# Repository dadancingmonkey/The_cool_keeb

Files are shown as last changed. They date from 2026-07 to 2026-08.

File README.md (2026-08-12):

The CoolKeeb

Description
The CoolKeeb is a cool custom keyboard that was fully designed and made by me. 
It is a general gaming keyboard that has a premium enclosure and bluetooth wireless cabilities whille retaining RGB illumination. 

It includes:
- custom PCB that hosues the switches
- Hotswappable sockets 
- exploded 75% format with 80 keys + a volume knob
- Nice!Nano MCU 
- 2000mAh battery 
- Cherry MX Brown switches
- Per-Key RGB illumination
- side printed PBT keycaps
- 3d printed & aluminum sheetmetal enclosure

images:
Screenshot 2026-07-09 at 5 52 30 PM
Screenshot 2026-07-09 at 5 53 01 PM
Screenshot 2026-07-09 at 5 53 17 PM

Schematics: 
Screenshot 2026-07-24 at 12 16 46 PM

PCB:


Assembly instructions:
- Solder the Kailh hot-swap inserts to the shield/keybaord board
- Solder all relavant components using schematic (diodes, LEDs, MCU, etc.)
- Attach MX switches to the keyboard plate
- Set MX switches into the hot-swap inserts
- Assemble the enclosure with 3D-printed parts and CNC aluminum parts.
- The case is essentially sandwiched using M3 screws, with the top 3D-printed elments being press-fit. 

Exploded view of enclosure assembly:
Screenshot 2026-07-24 at 11 02 27 PM

BOM: 
| Part | Price (USD) | Quantity | Source |
|---|---:|:---:|---|
| PBT keycaps, shine-through side printed | $17.65 | 1 | https://www.amazon.ca/dp/B0D1XK549B?psc=1&ref_=cm_sw_r_cp_ud_ct_RZ4HP9B0TKT2E4PN34CX |
| 466pcs M3 assorted screw kit | $12.00 | 1 | https://www.amazon.ca/dp/B0GCF8HZFR?psc=1&ref_=cm_sw_r_cp_ud_ct_RZ4HP9B0TKT2E4PN34CX_1 |
| 110pcs Kailh hot-swap PCB socket | $9.88 | 1 | https://www.aliexpress.com/item/1005012011087592.html |
| Cherry-style clear PCB-mounted stabilizers | $7.89 | 1 | https://www.aliexpress.com/item/32719735398.html |
| 50g rosin core solder | $5.04 | 1 | https://www.aliexpress.com/item/32889029087.html |
| NRF52840 dev board (Nice!Nano clone) | $4.00 | 1 | https://www.aliexpress.com/item/1005008594178678.html |
| 90pcs Cherry MX Brown RGB switches | $28.79 | 1 | https://www.aliexpress.com/item/1005008998414457.html |
| 5pcs round hole pin header | $3.12 | 1 | https://www.aliexpress.com/item/4001122376295.html |
| 100pcs JST PH 2-pin plug (male & female) | $1.99 | 1 | https://www.aliexpress.com/item/1005004955655144.html |
| 100pcs 1N4148WS T4 diodes | $3.45 | 1 | https://www.aliexpress.com/item/1005004309686841.html |
| 3.7V 2000mAh Li-Po battery | $7.08 | 1 | https://www.aliexpress.com/item/1005011848043177.html |
| 100pcs SK6803MINI-E LEDs | $10.86 | 1 | https://www.aliexpress.com/item/1005006968060177.html |
| Shipping (AliExpress) | $5.46 | 1 | N/A |
| EC11 rotary encoder | $0.00 | 1 | Me |
| PCB | $21.80 | 1 (5 pcs) | JLCPCB |
| Aluminum switch plate | $16.48 | 1 | JLCCNC |
| Aluminum cosmetic plate | $5.19 | 1 | JLCCNC |
| Aluminum bottom plate | $11.03 | 1 | JLCCNC |
| Aluminum bottom subframe plate | $10.40 | 1 | JLCCNC |
| PLA 3D printing filament + machine time | $5.00 | 1 | me |
| Shipping (JLCPCB/CNC, DHL Express) | $31.77 | 1 | DHL Express |

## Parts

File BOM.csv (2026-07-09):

part | price(USD) | quantity | source
PBT keycaps shinethrough side printed | $17.65 | 1 | https://www.amazon.ca/dp/B0D1XK549B?psc=1&ref_=cm_sw_r_cp_ud_ct_RZ4HP9B0TKT2E4PN34CX
466pcs M3 assorted screw kit | $12.00 | 1 | https://www.amazon.ca/dp/B0GCF8HZFR?psc=1&ref_=cm_sw_r_cp_ud_ct_RZ4HP9B0TKT2E4PN34CX_1
110pcs kailh Hot-swap PCB socket | $9.88 | 1 | https://www.aliexpress.com/item/1005012011087592.html?mp=1
Cherry Style clear PCB-mounted stabilizers | $7.89 | 1 | https://www.aliexpress.com/item/32719735398.html?mp=1
50g Rosin Core solder | $5.04 | 1 | https://www.aliexpress.com/item/32889029087.html?mp=1
NRF52840 dev board (Nice!Nano clone) | $4.00 | 1 | https://www.aliexpress.com/item/1005008594178678.html?mp=1
90pcs Cherry MX Brown RGB switch | $28.79 | 1 | https://www.aliexpress.com/item/1005008998414457.html?mp=1
5pcs round hole pin header | $3.12 | 1 | https://www.aliexpress.com/item/4001122376295.html?mp=1
100pcs JST PH 2 pin plug male and female | $1.99 | 1 | https://www.aliexpress.com/item/1005004955655144.html?mp=1
100pcs 1N4148WS T4 diode | $3.45 | 1 | https://www.aliexpress.com/item/1005004309686841.html?mp=1
3.7V 2000mAh Li-Po battery | $7.08 | 1 | https://www.aliexpress.com/item/1005011848043177.html?mp=1
100pcs SK6803MINI-E LED | $10.86 | 1 | https://www.aliexpress.com/item/1005006968060177.html?mp=1
Shipping (Aliexpress) | $5.46 | 1 | N/A
EC11 rotary encoder | $0.00 | 1 | me
PCB | $21.80 | 1(5) | JLCPCB
Aluminum switch plate | $16.48 | 1 | JLCCNC
Aluminum cosmetic plate | $5.19 | 1 | JLCCNC
Aluminum bottom plate | $11.03 | 1 | JLCCNC
Aluminum bottom subframe plate | $10.40 | 1 | JLCCNC
Shipping (JLCPCB/CNC) (global star shipping not availible due to weight) | $31.77 | 1 | DHL express

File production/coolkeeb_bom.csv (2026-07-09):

Designator | Footprint | Quantity | Value | LCSC Part #
D1, D10, D11, D12, D13, D14, D15, D16, D17, D18, D19, D2, D20, D21, D22, D23, D24, D25, D26, D27, D28, D29, D3, D30, D31, D32, D33, D34, D35, D36, D37, D38, D39, D4, D40, D41, D42, D43, D44, D45, D46, D47, D48, D49, D5, D50, D51, D52, D53, D54, D55, D56, D57, D58, D59, D6, D60, D61, D62, D63, D64, D65, D66, D67, D68, D69, D7, D70, D71, D72, D73, D74, D75, D76, D77, D78, D79, D8, D80, D81, D9 | D_SOD-323 | 81 | 1N4148WS | C57759
J1-BATTERY1 | JST_PH_S2B-PH-K_1x02_P2.00mm_Horizontal | 1 | Conn_01x02_Socket | C514173
LED1, LED10, LED11, LED12, LED13, LED2, LED29, LED3, LED30, LED31, LED32, LED33, LED34, LED35, LED36, LED37, LED38, LED39, LED4, LED40, LED41, LED42, LED43, LED5, LED58, LED59, LED6, LED60, LED61, LED62, LED63, LED64, LED65, LED66, LED67, LED68, LED69, LED7, LED70, LED8, LED9 | LED_MX_6028R-ROT | 41 | MX_SK6812MINI-E | C5242955
LED14, LED15, LED16, LED17, LED18, LED19, LED20, LED21, LED22, LED23, LED24, LED25, LED26, LED27, LED28, LED44, LED45, LED46, LED47, LED48, LED49, LED50, LED51, LED52, LED53, LED54, LED55, LED56, LED57, LED71, LED72, LED73, LED74, LED75, LED76, LED77, LED78, LED79, LED80, LED81, LED82 | LED_MX_6028R | 41 | MX_SK6812MINI-E | C5242955

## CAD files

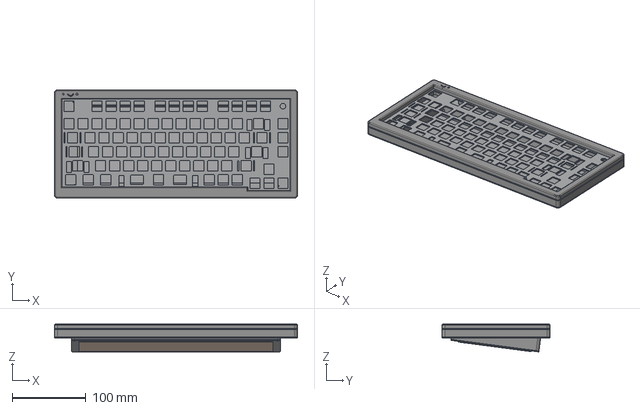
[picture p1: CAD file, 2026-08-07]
CAD/enclosure/assembled.step
329.9 x 147.0 x 37.7 mm

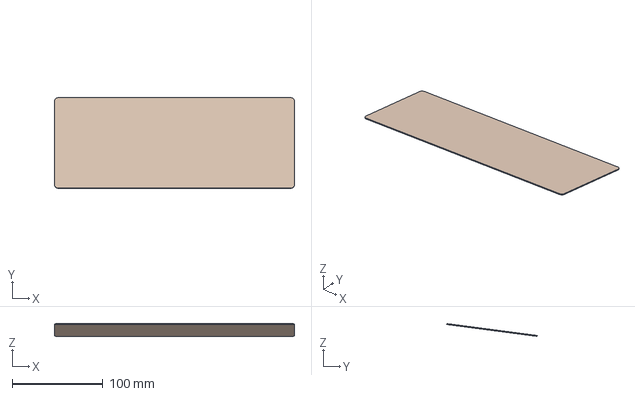
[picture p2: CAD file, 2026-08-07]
CAD/stl file/Part Studio 1 - Part 9.step
263.9 x 99.7 x 14.1 mm

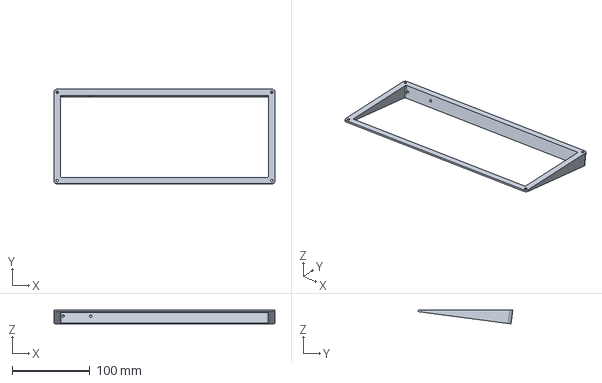
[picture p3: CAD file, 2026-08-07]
CAD/stl file/Part Studio 1 - Part 6.step
284.2 x 121.9 x 17.7 mm

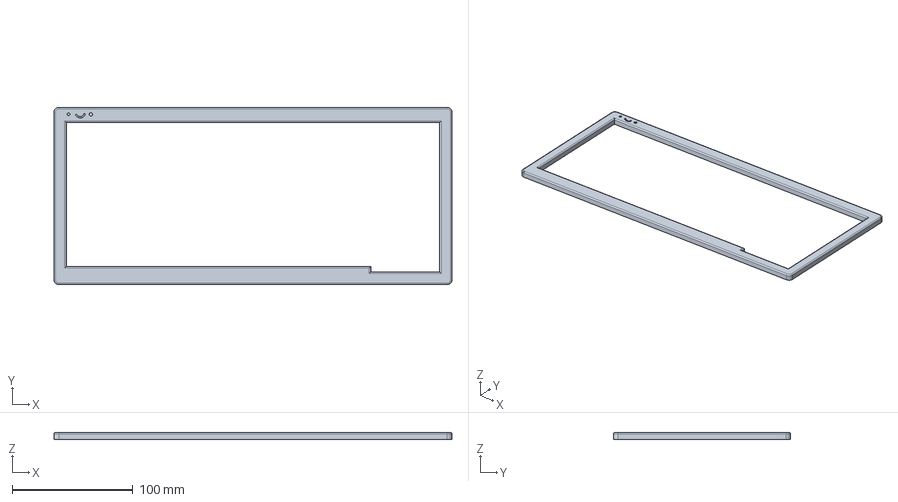
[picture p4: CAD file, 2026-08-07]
CAD/stl file/Part Studio 1 - Part 2.step
329.9 x 147.0 x 6.00 mm

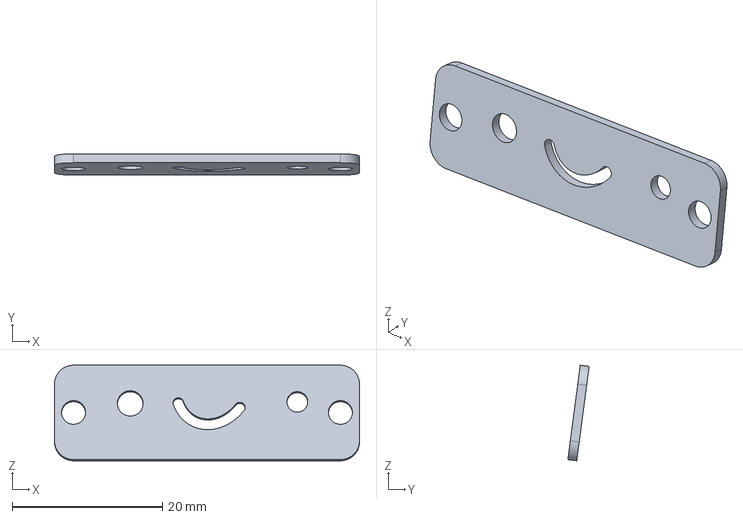
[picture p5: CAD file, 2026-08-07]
CAD/stl file/Part Studio 1 - Part 8.step
40.6 x 2.85 x 12.7 mm

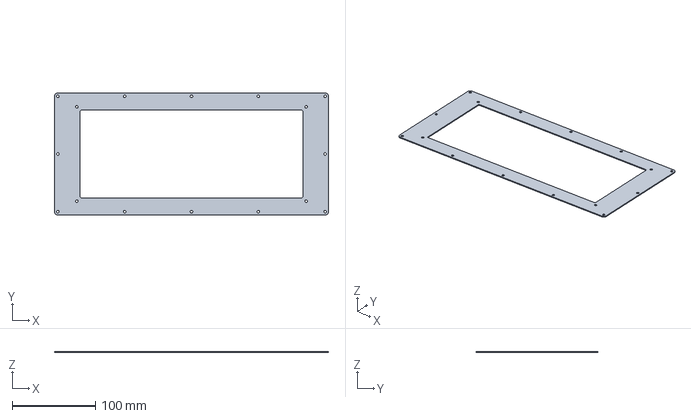
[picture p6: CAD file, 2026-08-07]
CAD/stl file/Part Studio 1 - Part 5.step
329.9 x 147.0 x 1.20 mm

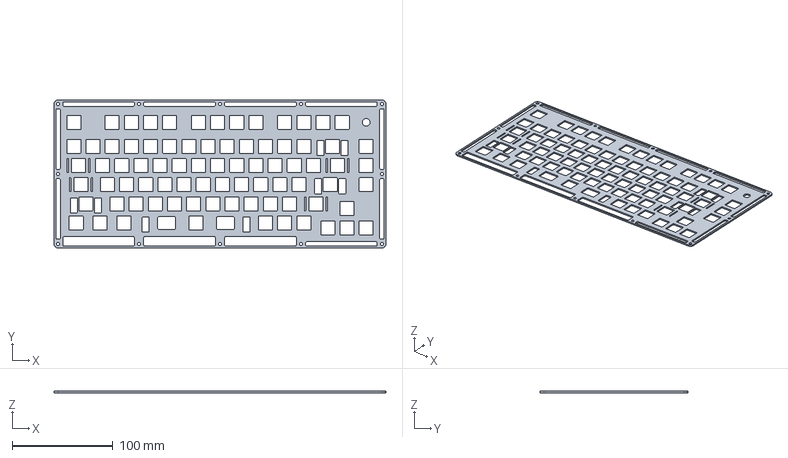
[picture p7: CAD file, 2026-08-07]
CAD/stl file/Part Studio 1 - Part 1.step
329.9 x 147.0 x 1.50 mm

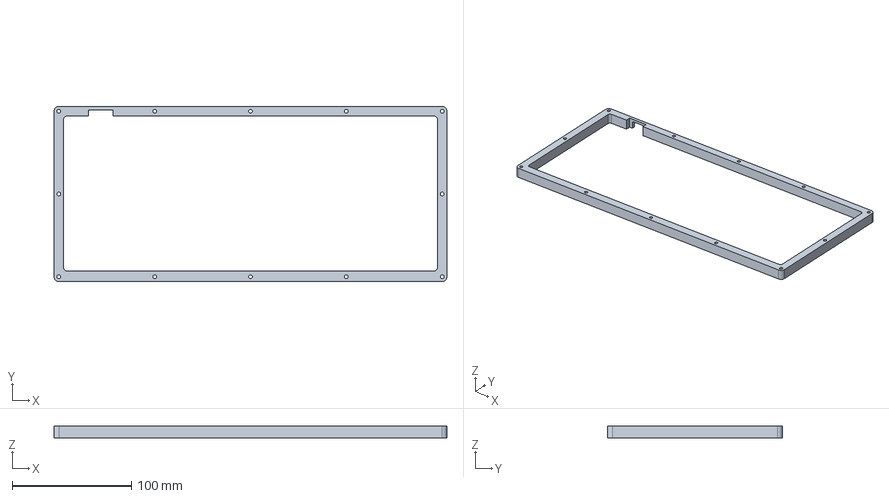
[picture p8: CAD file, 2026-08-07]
CAD/stl file/Part Studio 1 - Part 4.step
329.9 x 147.0 x 10.2 mm

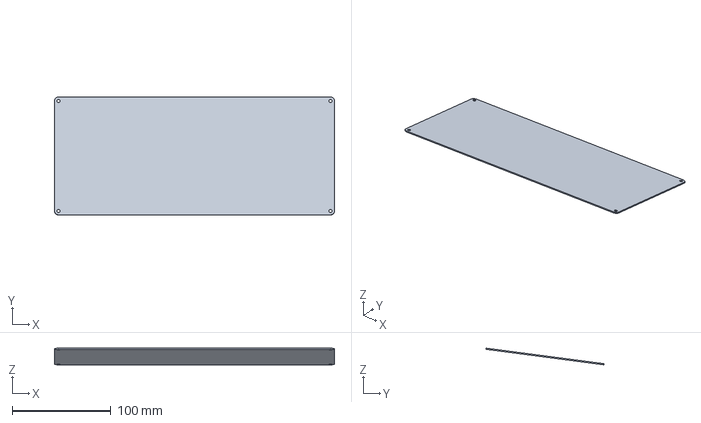
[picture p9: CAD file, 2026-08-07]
CAD/stl file/Part Studio 1 - Part 7.step
284.2 x 119.7 x 16.9 mm

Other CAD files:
CAD/enclosure/Part Studio 1 - Part 1.step
CAD/enclosure/Part Studio 1 - Part 8.step
CAD/enclosure/Part Studio 1 - Part 6.step
CAD/enclosure/Part Studio 1 - Part 2.step
CAD/enclosure/Part Studio 1 - Part 7.step
CAD/enclosure/Part Studio 1 - Part 5.step
CAD/enclosure/Part Studio 1 - Part 4.step
CAD/coolkeeb source/Part Studio 1 - Part 1.x_t
CAD/coolkeeb source/Part Studio 1 - Part 2.x_t
CAD/coolkeeb source/Part Studio 1 - Part 4.x_t
CAD/coolkeeb source/Part Studio 1 - Part 5.x_t
CAD/coolkeeb source/Part Studio 1 - Part 6.x_t
CAD/coolkeeb source/Part Studio 1 - Part 7.x_t
CAD/coolkeeb source/Part Studio 1 - Part 8.x_t
CAD/coolkeeb source/Part Studio 1 - Part 9.x_t

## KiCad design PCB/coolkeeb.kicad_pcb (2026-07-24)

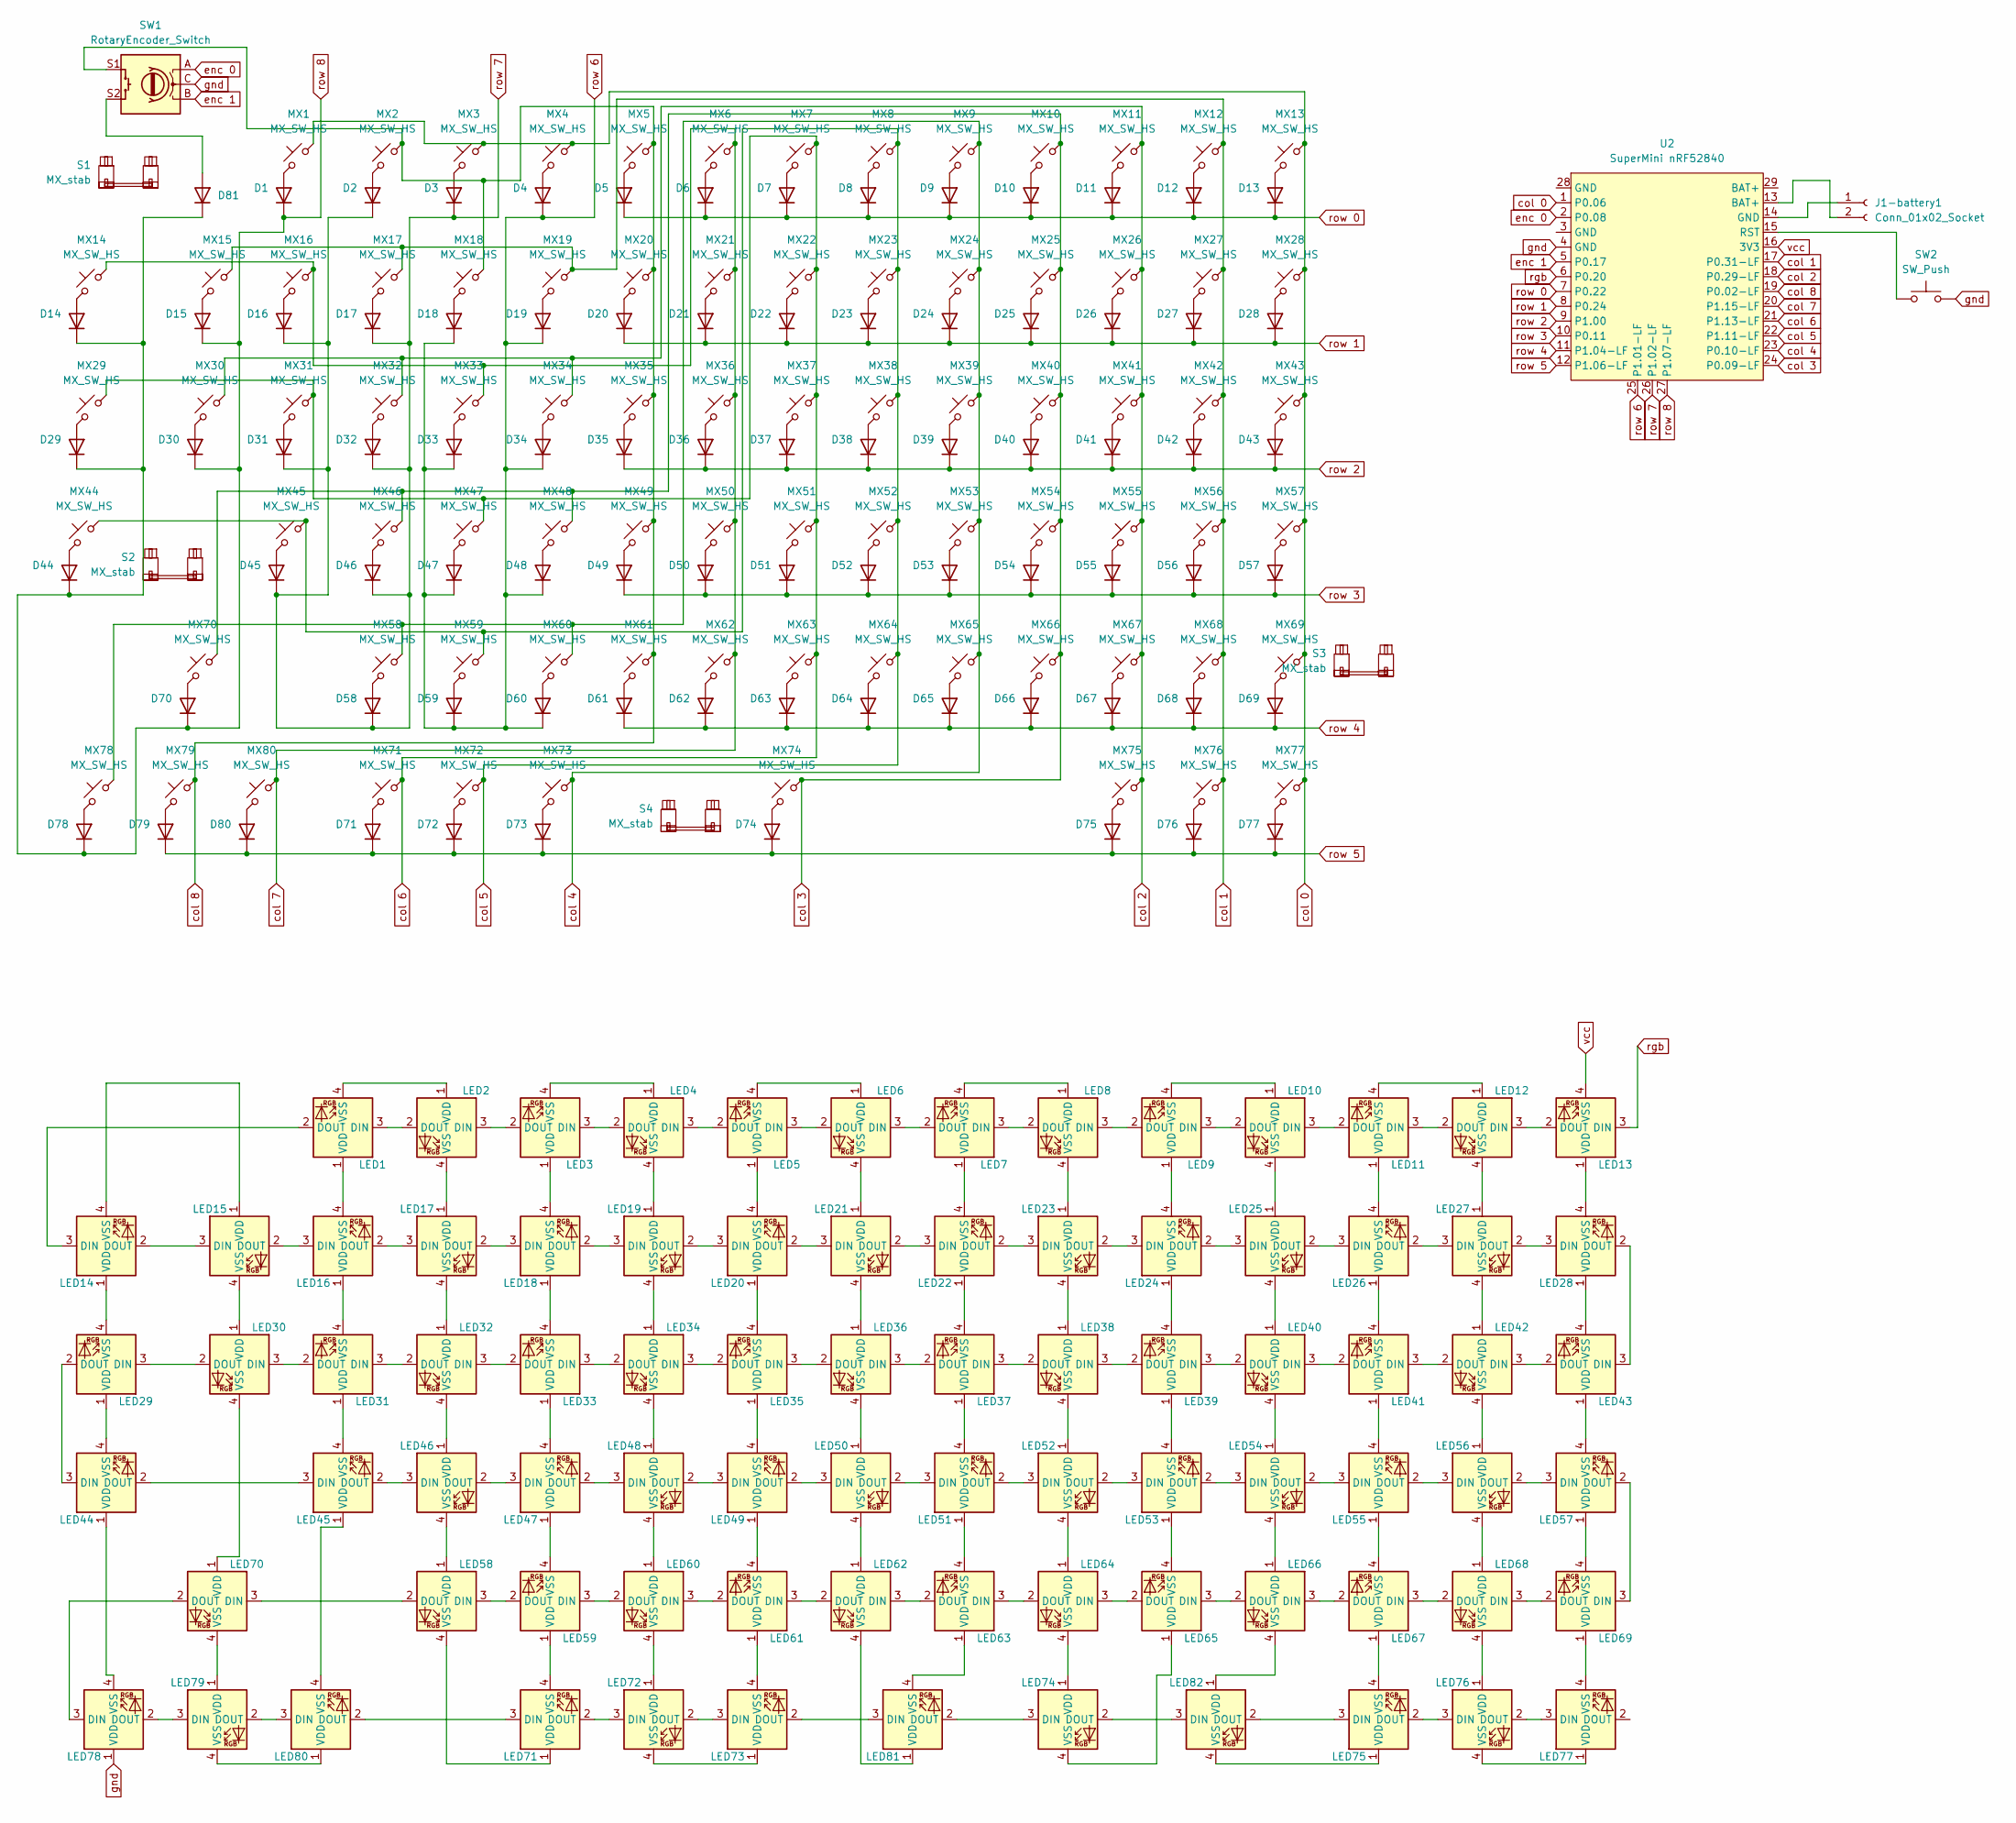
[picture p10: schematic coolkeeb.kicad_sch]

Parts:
D1, D2, D3, D4, D5, D6, D7, D8, D9, D10, D11, D12, D13, D14, D15, D16, D17, D18, D19, D20, D21, D22, D23, D24, D25, D26, D27, D28, D29, D30, D31, D32, D33, D34, D35, D36, D37, D38, D39, D40, D41, D42, D43, D44, D45, D46, D47, D48, D49, D50, D51, D52, D53, D54, D55, D56, D57, D58, D59, D60, D61, D62, D63, D64, D65, D66, D67, D68, D69, D70, D71, D72, D73, D74, D75, D76, D77, D78, D79, D80, D81: 1N4148WS; D_SOD-323; LCSC Part # C57759
J1-battery1: Conn_01x02_Socket; JST_PH_S2B-PH-K_1x02_P2.00mm_Horizontal; LCSC Part # C514173
LED1, LED2, LED3, LED4, LED5, LED6, LED7, LED8, LED9, LED10, LED11, LED12, LED13, LED29, LED30, LED31, LED32, LED33, LED34, LED35, LED36, LED37, LED38, LED39, LED40, LED41, LED42, LED43, LED58, LED59, LED60, LED61, LED62, LED63, LED64, LED65, LED66, LED67, LED68, LED69, LED70: MX_SK6812MINI-E; LED_MX_6028R-ROT; LCSC Part # C5242955
LED14, LED15, LED16, LED17, LED18, LED19, LED20, LED21, LED22, LED23, LED24, LED25, LED26, LED27, LED28, LED44, LED45, LED46, LED47, LED48, LED49, LED50, LED51, LED52, LED53, LED54, LED55, LED56, LED57, LED71, LED72, LED73, LED74, LED75, LED76, LED77, LED78, LED79, LED80, LED81, LED82: MX_SK6812MINI-E; LED_MX_6028R; LCSC Part # C5242955
MX1, MX2, MX3, MX4, MX5, MX6, MX7, MX8, MX9, MX10, MX11, MX12, MX13, MX14, MX15, MX16, MX17, MX18, MX19, MX20, MX21, MX22, MX23, MX24, MX25, MX26, MX27, MX28, MX29, MX30, MX31, MX32, MX33, MX34, MX35, MX36, MX37, MX38, MX39, MX40, MX41, MX42, MX43, MX44, MX45, MX46, MX47, MX48, MX49, MX50, MX51, MX52, MX53, MX54, MX55, MX56, MX57, MX58, MX59, MX60, MX61, MX62, MX63, MX64, MX65, MX66, MX67, MX68, MX69, MX70, MX71, MX72, MX73, MX74, MX75, MX76, MX77, MX78, MX79, MX80: MX_SW_HS; SW_MX_HS_CPG151101S11_1u
S1: MX_stab; STAB_MX_2u
S2, S3: MX_stab; STAB_MX_2.25u
S4: MX_stab; STAB_MX_P_6.25u
SW1: RotaryEncoder_Switch; RotaryEncoder_Alps_EC11E-Switch_Vertical_H20mm
SW2: SW_Push; SW_SPST_B3U-1000P
U2: SuperMini nRF52840; SuperMini_nRF52840_AH_USBup

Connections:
unnamed: D1.2 (A), MX1.2
unnamed: D2.2 (A), MX2.2
unnamed: D3.2 (A), MX3.2
unnamed: D4.2 (A), MX4.2
unnamed: D5.2 (A), MX5.2
unnamed: D6.2 (A), MX6.2
unnamed: D7.2 (A), MX7.2
unnamed: D8.2 (A), MX8.2
unnamed: D9.2 (A), MX9.2
unnamed: D10.2 (A), MX10.2
unnamed: D11.2 (A), MX11.2
unnamed: D12.2 (A), MX12.2
unnamed: D13.2 (A), MX13.2
unnamed: D14.2 (A), MX14.2
unnamed: D15.2 (A), MX15.2
unnamed: D16.2 (A), MX16.2
unnamed: D17.2 (A), MX17.2
unnamed: D18.2 (A), MX18.2
unnamed: D19.2 (A), MX19.2
unnamed: D20.2 (A), MX20.2
unnamed: D21.2 (A), MX21.2
unnamed: D22.2 (A), MX22.2
unnamed: D23.2 (A), MX23.2
unnamed: D24.2 (A), MX24.2
unnamed: D25.2 (A), MX25.2
unnamed: D26.2 (A), MX26.2
unnamed: D27.2 (A), MX27.2
unnamed: D28.2 (A), MX28.2
unnamed: D29.2 (A), MX29.2
unnamed: D30.2 (A), MX30.2
unnamed: D31.2 (A), MX31.2
unnamed: D32.2 (A), MX32.2
unnamed: D33.2 (A), MX33.2
unnamed: D34.2 (A), MX34.2
unnamed: D35.2 (A), MX35.2
unnamed: D36.2 (A), MX36.2
unnamed: D37.2 (A), MX37.2
unnamed: D38.2 (A), MX38.2
unnamed: D39.2 (A), MX39.2
unnamed: D40.2 (A), MX40.2
unnamed: D41.2 (A), MX41.2
unnamed: D42.2 (A), MX42.2
unnamed: D43.2 (A), MX43.2
unnamed: D44.2 (A), MX44.2
unnamed: D45.2 (A), MX45.2
unnamed: D46.2 (A), MX46.2
unnamed: D47.2 (A), MX47.2
unnamed: D48.2 (A), MX48.2
unnamed: D49.2 (A), MX49.2
unnamed: D50.2 (A), MX50.2
unnamed: D51.2 (A), MX51.2
unnamed: D52.2 (A), MX52.2
unnamed: D53.2 (A), MX53.2
unnamed: D54.2 (A), MX54.2
unnamed: D55.2 (A), MX55.2
unnamed: D56.2 (A), MX56.2
unnamed: D57.2 (A), MX57.2
unnamed: D58.2 (A), MX58.2
unnamed: D59.2 (A), MX59.2
unnamed: D60.2 (A), MX60.2
unnamed: D61.2 (A), MX61.2
unnamed: D62.2 (A), MX62.2
unnamed: D63.2 (A), MX63.2
unnamed: D64.2 (A), MX64.2
unnamed: D65.2 (A), MX65.2
unnamed: D66.2 (A), MX66.2
unnamed: D67.2 (A), MX67.2
unnamed: D68.2 (A), MX68.2
unnamed: D69.2 (A), MX69.2
unnamed: D70.2 (A), MX70.2
unnamed: D71.2 (A), MX71.2
unnamed: D72.2 (A), MX72.2
unnamed: D73.2 (A), MX73.2
unnamed: D74.2 (A), MX74.2
unnamed: D75.2 (A), MX75.2
unnamed: D76.2 (A), MX76.2
unnamed: D77.2 (A), MX77.2
unnamed: D78.2 (A), MX78.2
unnamed: D79.2 (A), MX79.2
unnamed: D80.2 (A), MX80.2
unnamed: D81.2 (A), SW1.S2
unnamed: J1-battery1.1, U2.14 (GND)
unnamed: J1-battery1.2, U2.13 (BAT+)
unnamed: LED1.3 (DIN), LED2.2 (DOUT)
unnamed: LED1.2 (DOUT), LED14.3 (DIN)
unnamed: LED1.1 (VDD), LED16.4 (VSS)
unnamed: LED1.4 (VSS), LED2.1 (VDD)
unnamed: LED2.3 (DIN), LED3.2 (DOUT)
unnamed: LED3.3 (DIN), LED4.2 (DOUT)
unnamed: LED3.4 (VSS), LED4.1 (VDD)
unnamed: LED4.3 (DIN), LED5.2 (DOUT)
unnamed: LED5.3 (DIN), LED6.2 (DOUT)
unnamed: LED5.4 (VSS), LED6.1 (VDD)
unnamed: LED6.3 (DIN), LED7.2 (DOUT)
unnamed: LED7.3 (DIN), LED8.2 (DOUT)
unnamed: LED7.4 (VSS), LED8.1 (VDD)
unnamed: LED8.3 (DIN), LED9.2 (DOUT)
unnamed: LED10.3 (DIN), LED11.2 (DOUT)
unnamed: LED9.3 (DIN), LED10.2 (DOUT)
unnamed: LED9.4 (VSS), LED10.1 (VDD)
unnamed: LED10.4 (VSS), LED25.1 (VDD)
unnamed: LED11.3 (DIN), LED12.2 (DOUT)
unnamed: LED11.1 (VDD), LED26.4 (VSS)
unnamed: LED11.4 (VSS), LED12.1 (VDD)
unnamed: LED12.3 (DIN), LED13.2 (DOUT)
unnamed: LED12.4 (VSS), LED27.1 (VDD)
unnamed: LED13.1 (VDD), LED28.4 (VSS)
unnamed: LED14.2 (DOUT), LED15.3 (DIN)
unnamed: LED14.1 (VDD), LED29.4 (VSS)
unnamed: LED14.4 (VSS), LED15.1 (VDD)
unnamed: LED15.2 (DOUT), LED16.3 (DIN)
unnamed: LED15.4 (VSS), LED30.1 (VDD)
unnamed: LED16.2 (DOUT), LED17.3 (DIN)
unnamed: LED16.1 (VDD), LED31.4 (VSS)
unnamed: LED17.2 (DOUT), LED18.3 (DIN)
unnamed: LED2.4 (VSS), LED17.1 (VDD)
unnamed: LED17.4 (VSS), LED32.1 (VDD)
unnamed: LED18.2 (DOUT), LED19.3 (DIN)
unnamed: LED18.1 (VDD), LED33.4 (VSS)
unnamed: LED3.1 (VDD), LED18.4 (VSS)
unnamed: LED19.2 (DOUT), LED20.3 (DIN)
unnamed: LED4.4 (VSS), LED19.1 (VDD)
unnamed: LED19.4 (VSS), LED34.1 (VDD)
unnamed: LED20.2 (DOUT), LED21.3 (DIN)
unnamed: LED20.1 (VDD), LED35.4 (VSS)
unnamed: LED5.1 (VDD), LED20.4 (VSS)
unnamed: LED21.2 (DOUT), LED22.3 (DIN)
unnamed: LED6.4 (VSS), LED21.1 (VDD)
unnamed: LED21.4 (VSS), LED36.1 (VDD)
unnamed: LED22.2 (DOUT), LED23.3 (DIN)
unnamed: LED22.1 (VDD), LED37.4 (VSS)
unnamed: LED7.1 (VDD), LED22.4 (VSS)
unnamed: LED23.2 (DOUT), LED24.3 (DIN)
unnamed: LED8.4 (VSS), LED23.1 (VDD)
unnamed: LED23.4 (VSS), LED38.1 (VDD)
unnamed: LED24.2 (DOUT), LED25.3 (DIN)
unnamed: LED24.1 (VDD), LED39.4 (VSS)
unnamed: LED9.1 (VDD), LED24.4 (VSS)
unnamed: LED25.2 (DOUT), LED26.3 (DIN)
unnamed: LED25.4 (VSS), LED40.1 (VDD)
unnamed: LED26.2 (DOUT), LED27.3 (DIN)
unnamed: LED26.1 (VDD), LED41.4 (VSS)
unnamed: LED27.2 (DOUT), LED28.3 (DIN)
unnamed: LED27.4 (VSS), LED42.1 (VDD)
unnamed: LED28.2 (DOUT), LED43.3 (DIN)
unnamed: LED28.1 (VDD), LED43.4 (VSS)
unnamed: LED29.3 (DIN), LED30.2 (DOUT)
unnamed: LED29.2 (DOUT), LED44.3 (DIN)
unnamed: LED29.1 (VDD), LED44.4 (VSS)
unnamed: LED30.3 (DIN), LED31.2 (DOUT)
unnamed: LED30.4 (VSS), LED70.1 (VDD)
unnamed: LED31.3 (DIN), LED32.2 (DOUT)
unnamed: LED31.1 (VDD), LED45.4 (VSS)
unnamed: LED32.3 (DIN), LED33.2 (DOUT)
unnamed: LED32.4 (VSS), LED46.1 (VDD)
unnamed: LED33.3 (DIN), LED34.2 (DOUT)
unnamed: LED33.1 (VDD), LED47.4 (VSS)
unnamed: LED34.3 (DIN), LED35.2 (DOUT)
unnamed: LED34.4 (VSS), LED48.1 (VDD)
unnamed: LED35.3 (DIN), LED36.2 (DOUT)
unnamed: LED35.1 (VDD), LED49.4 (VSS)
unnamed: LED36.3 (DIN), LED37.2 (DOUT)
unnamed: LED36.4 (VSS), LED50.1 (VDD)
unnamed: LED37.3 (DIN), LED38.2 (DOUT)
unnamed: LED37.1 (VDD), LED51.4 (VSS)
unnamed: LED38.3 (DIN), LED39.2 (DOUT)
unnamed: LED38.4 (VSS), LED52.1 (VDD)
unnamed: LED39.3 (DIN), LED40.2 (DOUT)
unnamed: LED39.1 (VDD), LED53.4 (VSS)
unnamed: LED40.3 (DIN), LED41.2 (DOUT)
unnamed: LED40.4 (VSS), LED54.1 (VDD)
unnamed: LED41.3 (DIN), LED42.2 (DOUT)
unnamed: LED41.1 (VDD), LED55.4 (VSS)
unnamed: LED42.3 (DIN), LED43.2 (DOUT)
unnamed: LED42.4 (VSS), LED56.1 (VDD)
unnamed: LED43.1 (VDD), LED57.4 (VSS)
unnamed: LED44.2 (DOUT), LED45.3 (DIN)
unnamed: LED44.1 (VDD), LED78.4 (VSS)
unnamed: LED45.2 (DOUT), LED46.3 (DIN)
unnamed: LED45.1 (VDD), LED80.4 (VSS)
unnamed: LED46.2 (DOUT), LED47.3 (DIN)
unnamed: LED46.4 (VSS), LED58.1 (VDD)
unnamed: LED47.2 (DOUT), LED48.3 (DIN)
unnamed: LED47.1 (VDD), LED59.4 (VSS)
unnamed: LED48.2 (DOUT), LED49.3 (DIN)
unnamed: LED48.4 (VSS), LED60.1 (VDD)
unnamed: LED49.2 (DOUT), LED50.3 (DIN)
unnamed: LED49.1 (VDD), LED61.4 (VSS)
unnamed: LED50.2 (DOUT), LED51.3 (DIN)
unnamed: LED50.4 (VSS), LED62.1 (VDD)
unnamed: LED51.2 (DOUT), LED52.3 (DIN)
unnamed: LED51.1 (VDD), LED63.4 (VSS)
unnamed: LED52.2 (DOUT), LED53.3 (DIN)
unnamed: LED52.4 (VSS), LED64.1 (VDD)
unnamed: LED53.2 (DOUT), LED54.3 (DIN)
unnamed: LED53.1 (VDD), LED65.4 (VSS)
unnamed: LED54.2 (DOUT), LED55.3 (DIN)
unnamed: LED54.4 (VSS), LED66.1 (VDD)
unnamed: LED55.2 (DOUT), LED56.3 (DIN)
unnamed: LED55.1 (VDD), LED67.4 (VSS)
unnamed: LED56.2 (DOUT), LED57.3 (DIN)
unnamed: LED56.4 (VSS), LED68.1 (VDD)
unnamed: LED57.2 (DOUT), LED69.3 (DIN)
unnamed: LED57.1 (VDD), LED69.4 (VSS)
unnamed: LED58.3 (DIN), LED59.2 (DOUT)
unnamed: LED58.2 (DOUT), LED70.3 (DIN)
unnamed: LED58.4 (VSS), LED71.1 (VDD)
unnamed: LED59.3 (DIN), LED60.2 (DOUT)
unnamed: LED59.1 (VDD), LED71.4 (VSS)
unnamed: LED60.3 (DIN), LED61.2 (DOUT)
unnamed: LED60.4 (VSS), LED72.1 (VDD)
unnamed: LED61.3 (DIN), LED62.2 (DOUT)
unnamed: LED61.1 (VDD), LED73.4 (VSS)
unnamed: LED62.3 (DIN), LED63.2 (DOUT)
unnamed: LED62.4 (VSS), LED81.1 (VDD)
unnamed: LED63.3 (DIN), LED64.2 (DOUT)
unnamed: LED63.1 (VDD), LED81.4 (VSS)
unnamed: LED64.3 (DIN), LED65.2 (DOUT)
unnamed: LED64.4 (VSS), LED74.1 (VDD)
unnamed: LED65.3 (DIN), LED66.2 (DOUT)
unnamed: LED65.1 (VDD), LED74.4 (VSS)
unnamed: LED66.3 (DIN), LED67.2 (DOUT)
unnamed: LED66.4 (VSS), LED82.1 (VDD)
unnamed: LED67.3 (DIN), LED68.2 (DOUT)
unnamed: LED67.1 (VDD), LED75.4 (VSS)
unnamed: LED68.3 (DIN), LED69.2 (DOUT)
unnamed: LED68.4 (VSS), LED76.1 (VDD)
unnamed: LED69.1 (VDD), LED77.4 (VSS)
unnamed: LED70.2 (DOUT), LED78.3 (DIN)
unnamed: LED70.4 (VSS), LED79.1 (VDD)
unnamed: LED71.3 (DIN), LED80.2 (DOUT)
unnamed: LED71.2 (DOUT), LED72.3 (DIN)
unnamed: LED72.2 (DOUT), LED73.3 (DIN)
unnamed: LED72.4 (VSS), LED73.1 (VDD)
unnamed: LED73.2 (DOUT), LED81.3 (DIN)
unnamed: LED74.3 (DIN), LED81.2 (DOUT)
unnamed: LED74.2 (DOUT), LED82.3 (DIN)
unnamed: LED75.3 (DIN), LED82.2 (DOUT)
unnamed: LED75.2 (DOUT), LED76.3 (DIN)
unnamed: LED75.1 (VDD), LED82.4 (VSS)
unnamed: LED76.2 (DOUT), LED77.3 (DIN)
unnamed: LED76.4 (VSS), LED77.1 (VDD)
unnamed: LED78.2 (DOUT), LED79.3 (DIN)
unnamed: LED79.2 (DOUT), LED80.3 (DIN)
unnamed: LED79.4 (VSS), LED80.1 (VDD)
unnamed: SW2.1, U2.15 (RST)
col 0: MX1.1, MX3.1, MX4.1, MX13.1, MX28.1, MX43.1, MX57.1, MX69.1, MX77.1, U2.1 (P0.06)
col 1: MX12.1, MX15.1, MX17.1, MX19.1, MX27.1, MX42.1, MX56.1, MX68.1, MX76.1, U2.17 (P0.31-LF)
col 2: MX11.1, MX26.1, MX30.1, MX32.1, MX34.1, MX41.1, MX55.1, MX67.1, MX75.1, U2.18 (P0.29-LF)
col 3: MX10.1, MX25.1, MX40.1, MX46.1, MX48.1, MX54.1, MX66.1, MX70.1, MX74.1, U2.24 (P0.09-LF)
col 4: MX9.1, MX24.1, MX39.1, MX53.1, MX58.1, MX60.1, MX65.1, MX73.1, MX78.1, U2.23 (P0.10-LF)
col 5: MX8.1, MX23.1, MX38.1, MX44.1, MX45.1, MX52.1, MX59.1, MX64.1, MX72.1, U2.22 (P1.11-LF)
col 6: MX7.1, MX22.1, MX29.1, MX31.1, MX37.1, MX47.1, MX51.1, MX63.1, MX71.1, U2.21 (P1.13-LF)
col 7: MX6.1, MX14.1, MX16.1, MX21.1, MX33.1, MX36.1, MX50.1, MX62.1, MX80.1, U2.20 (P1.15-LF)
col 8: MX2.1, MX5.1, MX18.1, MX20.1, MX35.1, MX49.1, MX61.1, MX79.1, SW1.S1, U2.19 (P0.02-LF)
enc 0: SW1.A, U2.2 (P0.08)
enc 1: SW1.B, U2.5 (P0.17)
gnd: LED78.1 (VDD), SW1.C, SW2.2, U2.4 (GND)
rgb: LED13.3 (DIN), U2.6 (P0.20)
row 0: D5.1 (K), D6.1 (K), D7.1 (K), D8.1 (K), D9.1 (K), D10.1 (K), D11.1 (K), D12.1 (K), D13.1 (K), U2.7 (P0.22)
row 1: D20.1 (K), D21.1 (K), D22.1 (K), D23.1 (K), D24.1 (K), D25.1 (K), D26.1 (K), D27.1 (K), D28.1 (K), U2.8 (P0.24)
row 2: D35.1 (K), D36.1 (K), D37.1 (K), D38.1 (K), D39.1 (K), D40.1 (K), D41.1 (K), D42.1 (K), D43.1 (K), U2.9 (P1.00)
row 3: D49.1 (K), D50.1 (K), D51.1 (K), D52.1 (K), D53.1 (K), D54.1 (K), D55.1 (K), D56.1 (K), D57.1 (K), U2.10 (P0.11)
row 4: D61.1 (K), D62.1 (K), D63.1 (K), D64.1 (K), D65.1 (K), D66.1 (K), D67.1 (K), D68.1 (K), D69.1 (K), U2.11 (P1.04-LF)
row 5: D71.1 (K), D72.1 (K), D73.1 (K), D74.1 (K), D75.1 (K), D76.1 (K), D77.1 (K), D79.1 (K), D80.1 (K), U2.12 (P1.06-LF)
row 6: D4.1 (K), D18.1 (K), D19.1 (K), D33.1 (K), D34.1 (K), D47.1 (K), D48.1 (K), D59.1 (K), D60.1 (K), U2.25 (P1.01-LF)
row 7: D2.1 (K), D3.1 (K), D16.1 (K), D17.1 (K), D31.1 (K), D32.1 (K), D45.1 (K), D46.1 (K), D58.1 (K), U2.26 (P1.02-LF)
row 8: D1.1 (K), D14.1 (K), D15.1 (K), D29.1 (K), D30.1 (K), D44.1 (K), D70.1 (K), D78.1 (K), D81.1 (K), U2.27 (P1.07-LF)
vcc: LED13.4 (VSS), U2.16 (3V3)

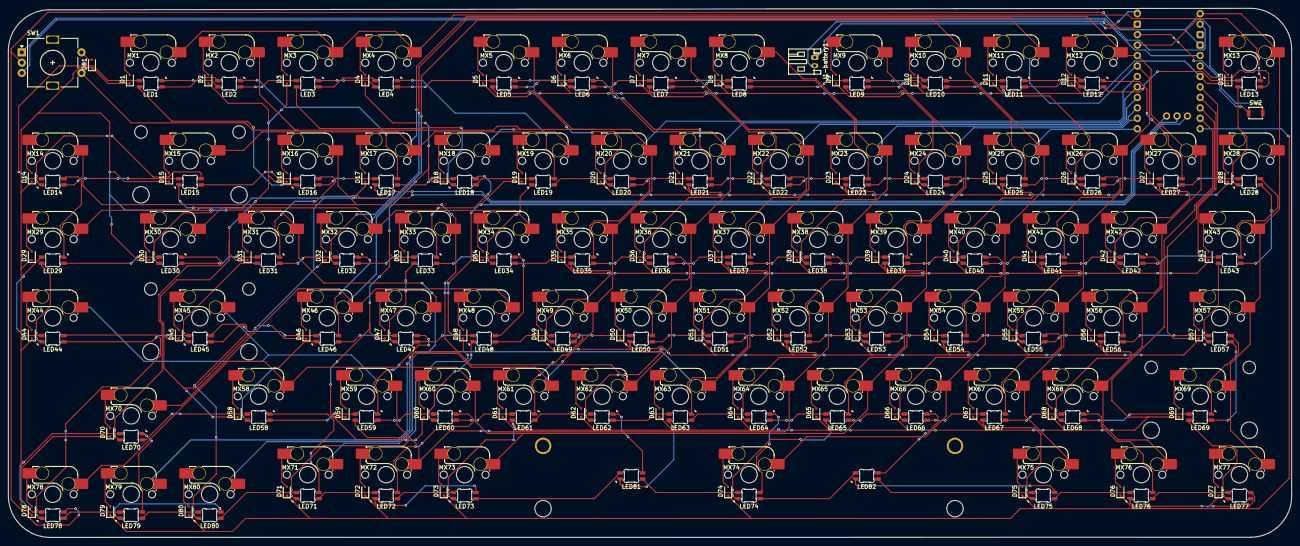
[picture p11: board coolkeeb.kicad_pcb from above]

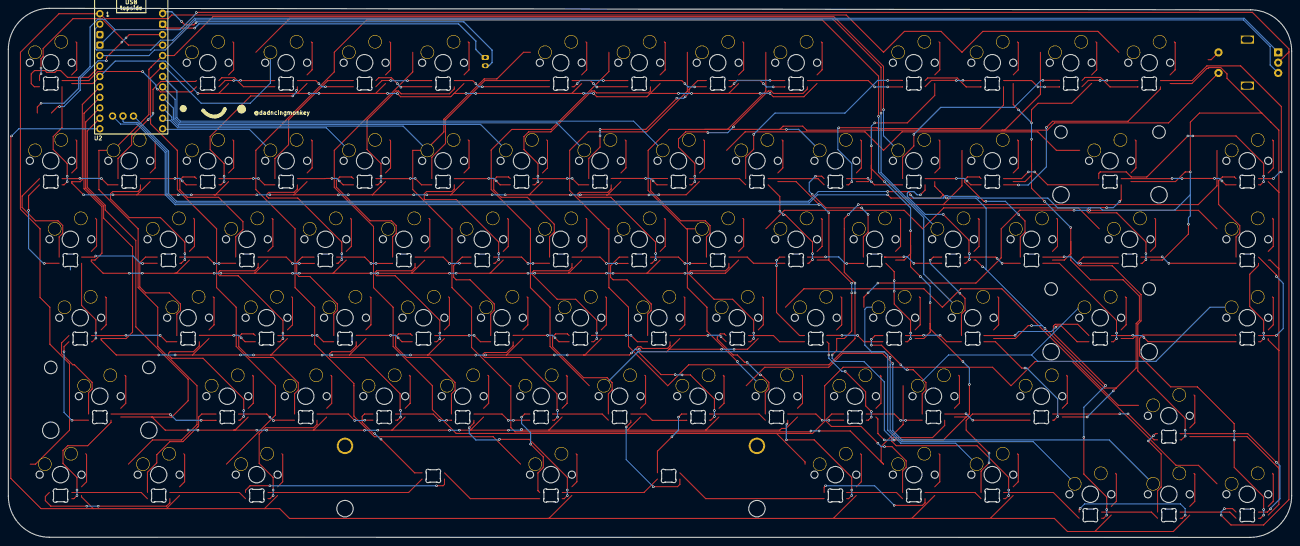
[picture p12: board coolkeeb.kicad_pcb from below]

Board: 2 copper layers, 311.6 x 128.5 mm, 251 parts (5 on the bottom side), 269 nets.

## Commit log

2026-07-09 made requested changes
    [BOM.csv, Part Studio 1 - Part 1.step, Part Studio 1 - Part 2.step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]
2026-07-25 Update README with exploded view and BOM details
    Added an exploded view image of the enclosure assembly and included PLA 3D printing filament in the BOM.
2026-07-25 Replace enclosure assembly image in README
    Updated the image in the README to a new screenshot.
2026-08-07 Update README with PCB image and assembly steps
    Added PCB image and assembly instructions to README.
2026-08-12 Change PLA 3D printing filament price to $5.00
    Updated the price of PLA 3D printing filament and machine time.
